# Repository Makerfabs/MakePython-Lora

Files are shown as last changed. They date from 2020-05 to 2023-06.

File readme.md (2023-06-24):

# MakePython Lora

```c++
/*
Version:		V2.1
Author:			Vincent
Create Date:	2020/7/24
Note:
2021/8/18		V2.1 Fix Lora Gateway 915M bug.
2020/12/11		V2.0 Now supply arduino lib: RadioLib
2022/8/15		V2.1 Update new RadioLib demo
*/
```

[toc]

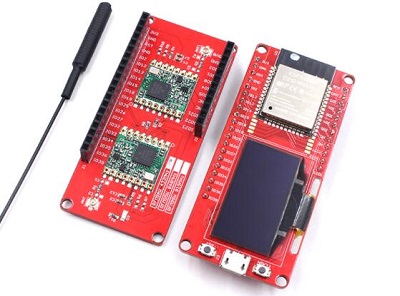
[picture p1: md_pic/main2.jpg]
main2


# Makerfabs

[Makerfabs home page](https://www.makerfabs.com/)

[Makerfabs Wiki](https://wiki.makerfabs.com/)

# Introduce

The Makepython Lora transceivers feature the LoRaTM long range modem that provides ultra-long range spread spectrum communication and high interference immunity whilst minimising current consumption.

Product Link ： [MakePython Lora](https://www.makerfabs.com/esp32-lora-gateway.html)

Wiki Link : [MakePython Lora Wiki](https://wiki.makerfabs.com/MaESP_ESP32_Lora_Gateway.html)

## Front

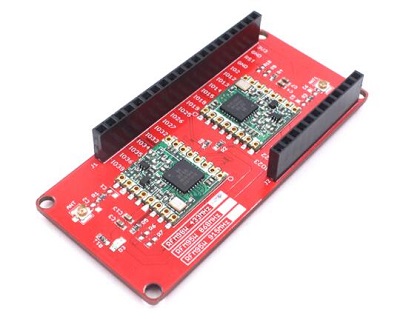
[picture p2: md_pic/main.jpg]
main


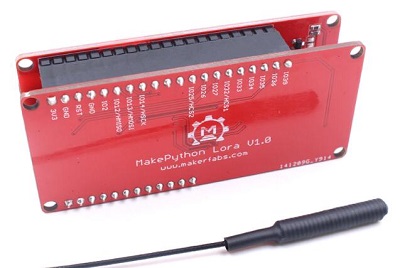
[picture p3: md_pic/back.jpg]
back


# RadioLib Example

## send_and_receive.ino

A demo for communicating with the standard Makerfabs LoraNode (MaLora).

All Lora Nodes use this Lora library: [RadioLib](https://github.com/jgromes/RadioLib)

**It is recommended to install from Arduino Library Manager and select the library version 4.6.0. RadioLib libraries after 5.0 need to add "RADIOLIB_" before some macro definitions.**

The current firmware is developed in RadioLib 4.6.0.

## MaLora

**MaLora** is Makerfabs Loranode.

Makerfabs Lora Node is a series of products based on Arduino Pro Mini (328P) + Lora(SX127X). 

Like Relay, AC Dimmer, MOSFET, etc.

For easy to use, UID and generic instructions are provided. Some of them are our previous products, but have not added UID yet. 

[MaLora](https://github.com/Makerfabs/Makerfabs_MaLora)

*We started with MicroPython, but the Lora library support was not good. There was also a failure to communicate with other Lora libraries. So we discontinued MicroPython maintenance, and subsequent Makerfabs Lora-related products use the agreed Lora library.*

## Test

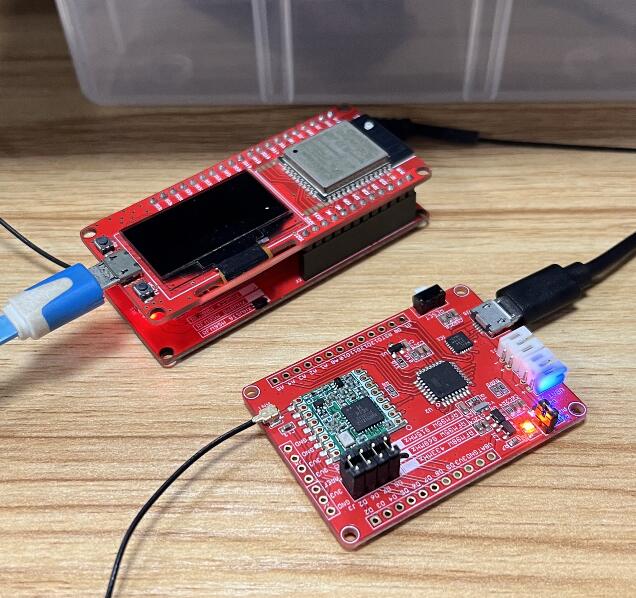
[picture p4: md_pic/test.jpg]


Communicates with a standard Lora Node. The code used by Maduino Lora Radio is in:

 [LoraNodeDemo](https://github.com/Makerfabs/Makerfabs_MaLora/tree/main/MaduinoLoraRadio/firmware/LoraNodeDemo)

Serial Monitor Display:

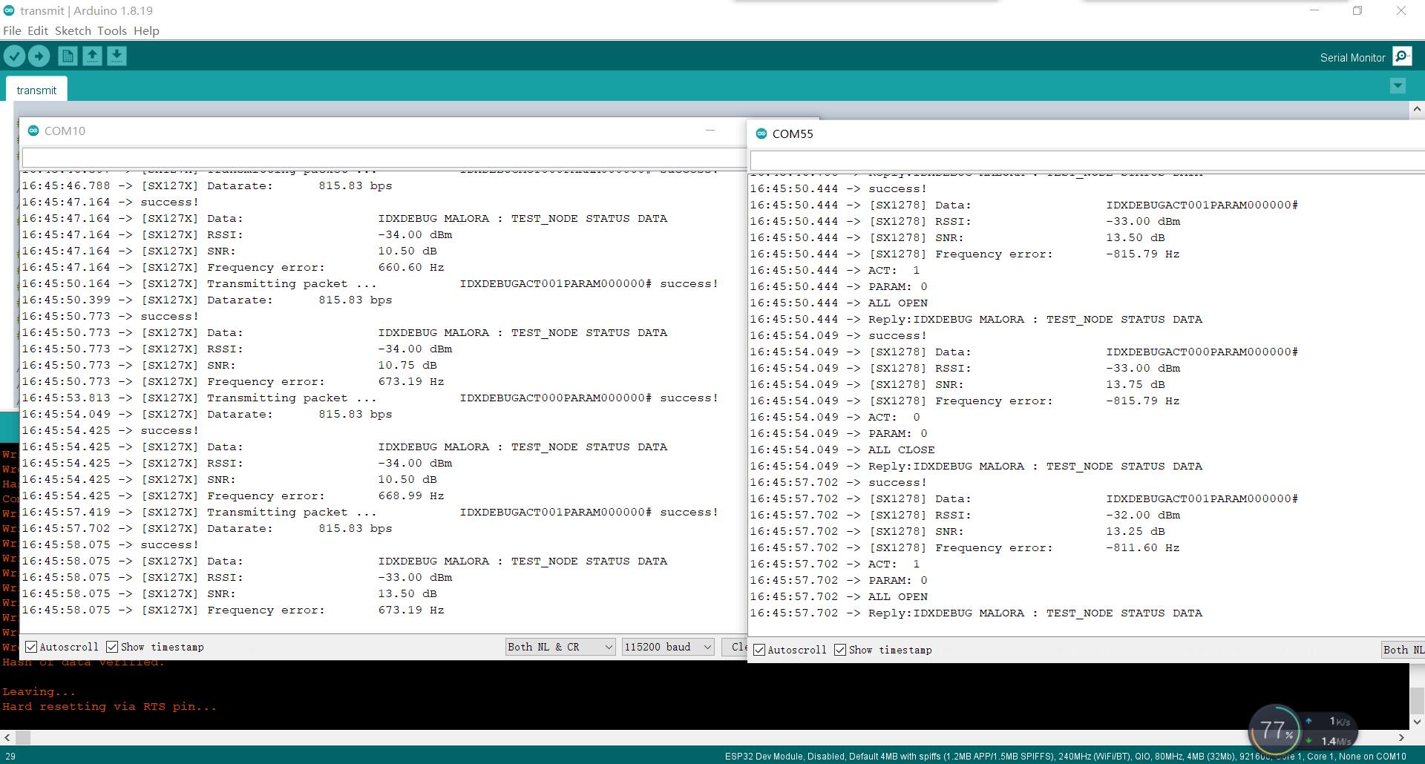
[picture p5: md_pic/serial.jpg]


# Related Tests

- Long distance Lora communication

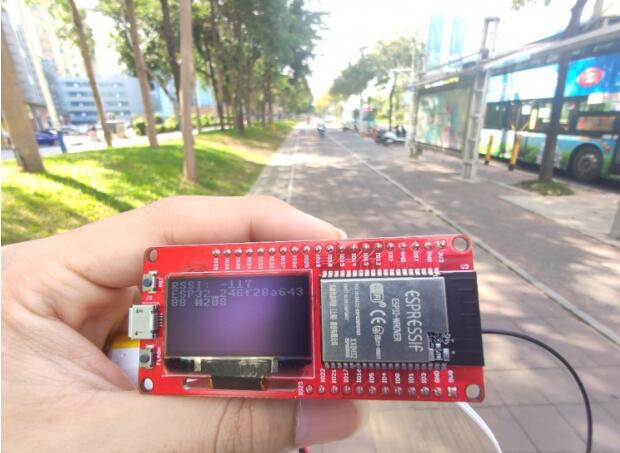
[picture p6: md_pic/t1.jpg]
t1


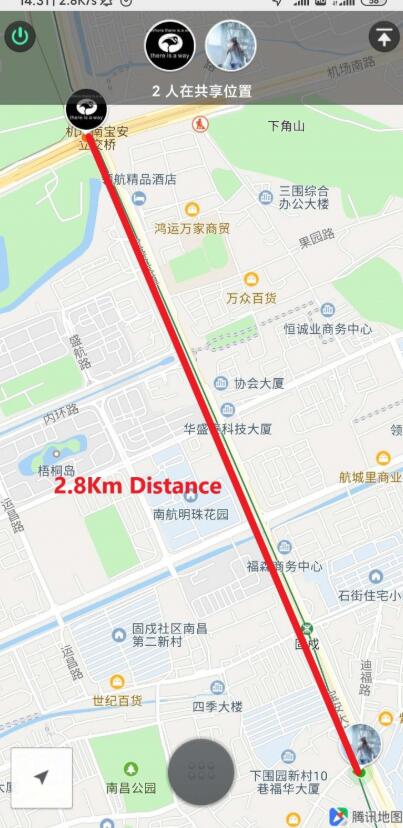
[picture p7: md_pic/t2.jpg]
t2


# Related Projects

## [Project_IoT Irrigation System](https://github.com/Makerfabs/Project_IoT-Irrigation-System)

- IoT agricultural irrigation experiment based on Lora communication.
- [YOUTUBE:Lora IoT Irrigation System - Outdoor Simulation Test](https://youtu.be/0mY6Ox0YvRk)

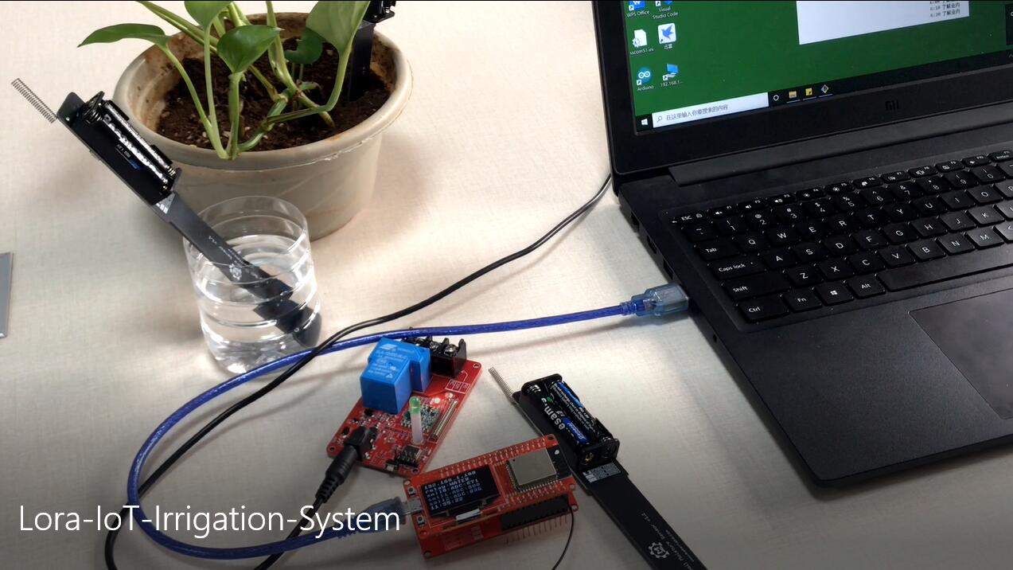
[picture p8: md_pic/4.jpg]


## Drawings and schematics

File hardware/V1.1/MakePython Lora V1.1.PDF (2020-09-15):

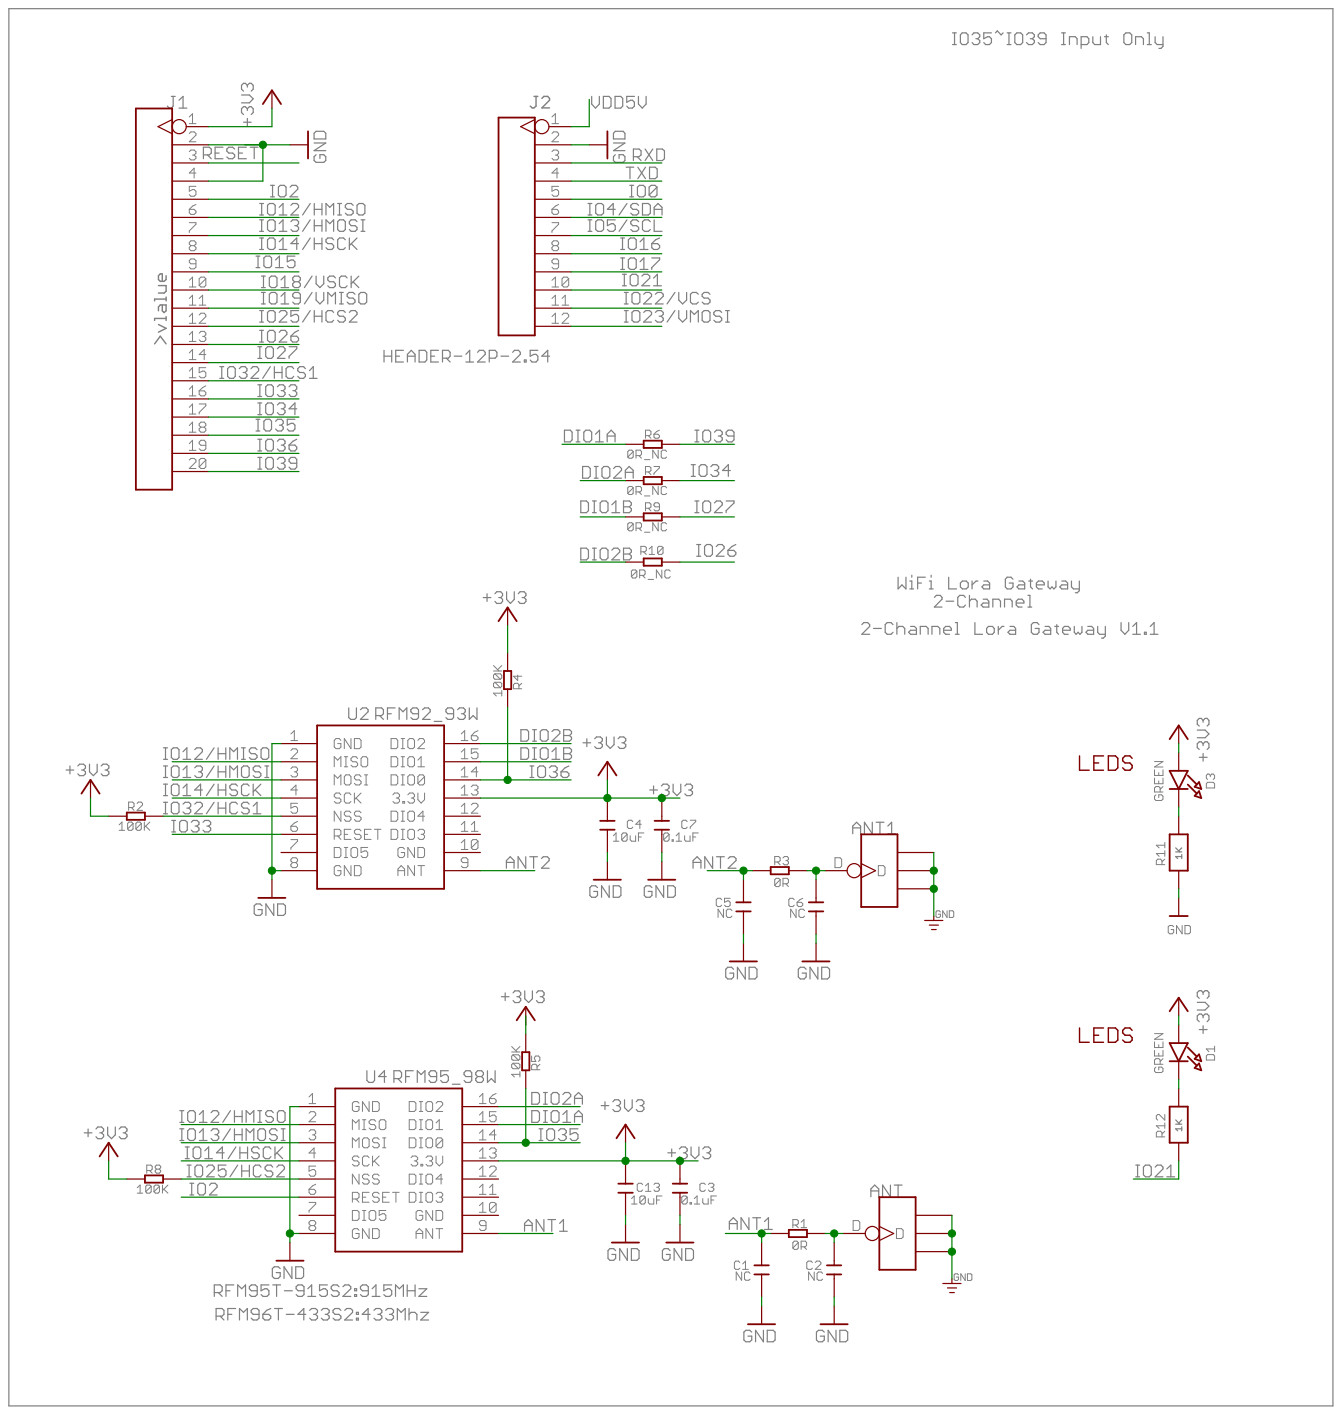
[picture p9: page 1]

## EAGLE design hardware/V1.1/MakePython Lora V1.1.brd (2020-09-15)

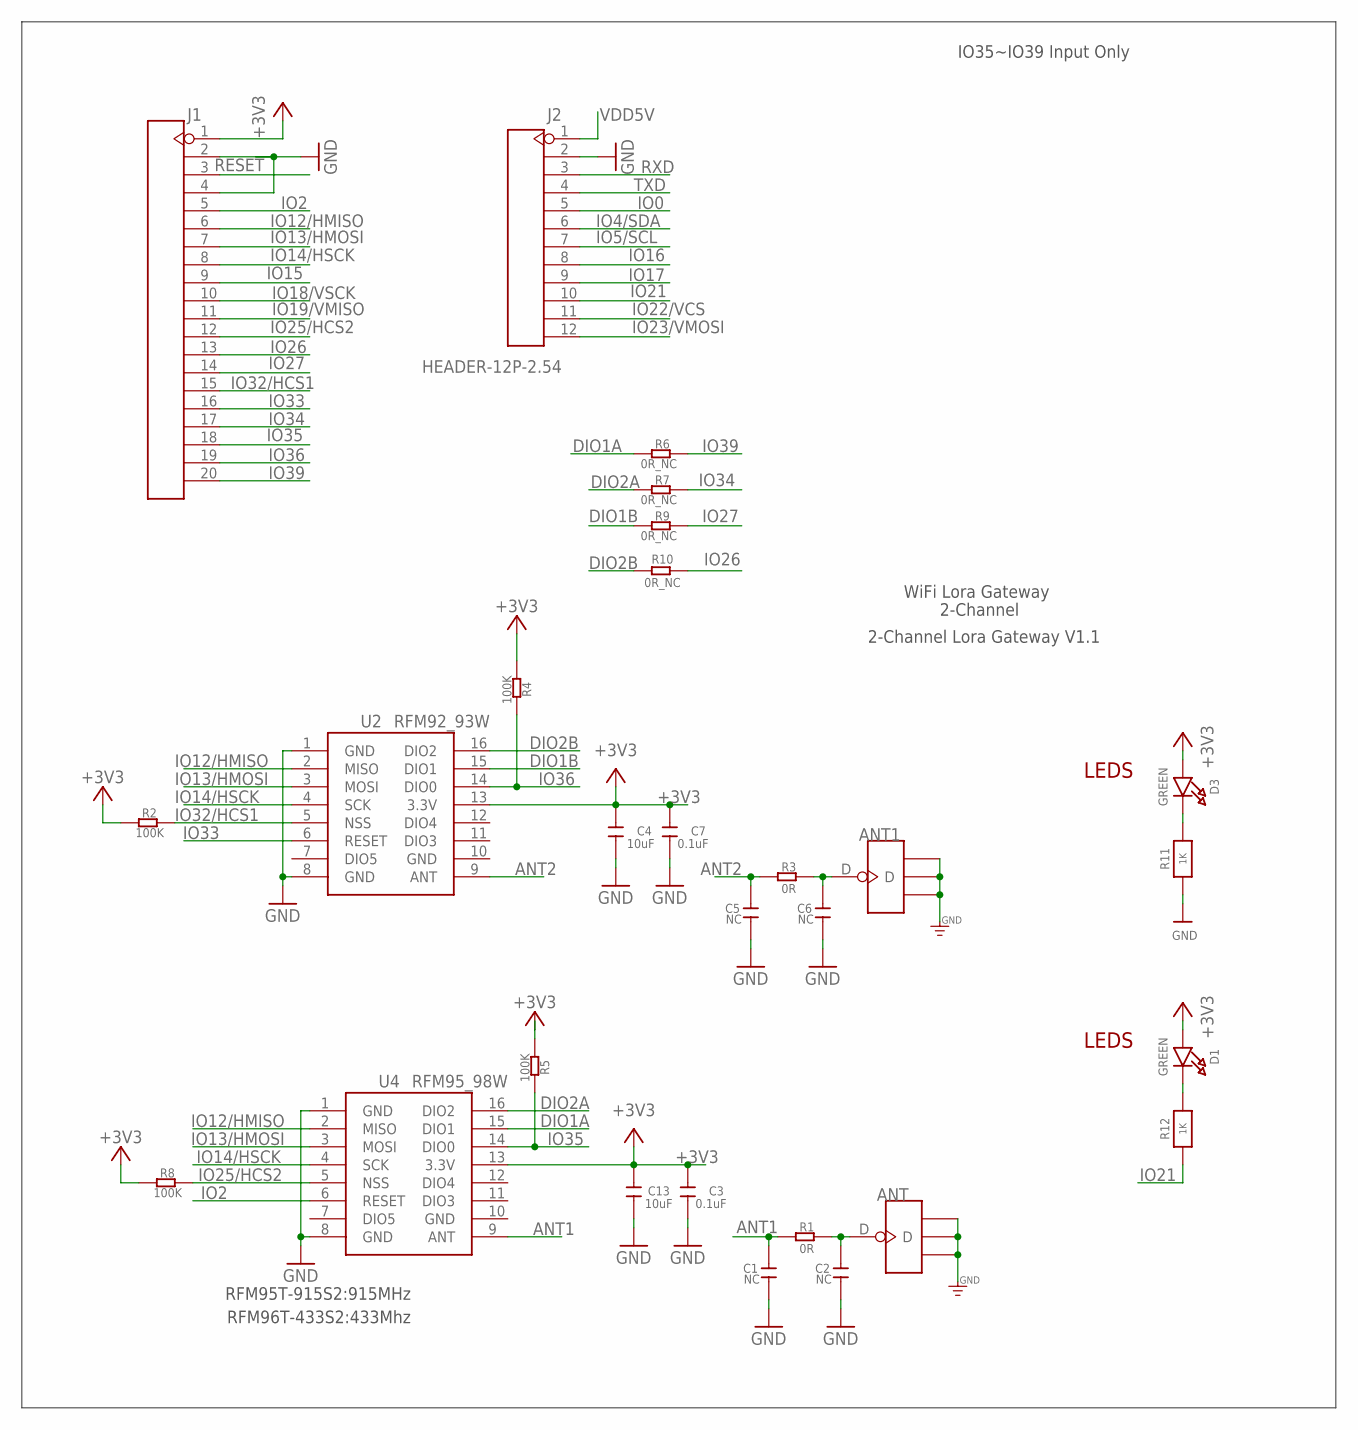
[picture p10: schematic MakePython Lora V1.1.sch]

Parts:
ANT, ANT1: ANTENNA-U-FL; 4P-U-FL
C1, C2, C5, C6: NC; DISCRETE_C0603
C3, C7: 0.1uF; 0603
C4, C13: 10uF; 0603
D1, D3: GREEN; CHIPLED_0805_NOOUTLINE
J1: HEADER-20P-2.54; 20P-2.54
J2: HEADER-12P-2.54; 12P-2.54
R1, R3: 0R; DISCRETE_R0603
R2, R4, R5, R8: 100K; R0603
R6, R7, R9, R10: 0R_NC; R0603
R11, R12: 1K; 0603-NO
U2: RFM92_93W
U4: RFM95_98W; RFM92_93W

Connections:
+3V3: C3.2, C4.2, C7.2, C13.2, D1.A, D3.A, J1.1, R2.2, R4.2, R5.2, R8.2, U2.13 (3.3V), U4.13 (3.3V)
ANT1: C1.2, R1.1, U4.9 (ANT)
ANT2: C5.2, R3.1, U2.9 (ANT)
DIO1A: R6.2, U4.15 (DIO1)
DIO1B: R9.2, U2.15 (DIO1)
DIO2A: R7.2, U4.16 (DIO2)
DIO2B: R10.2, U2.16 (DIO2)
GND: ANT.GND1, ANT.GND2, ANT.GND3, ANT1.GND1, ANT1.GND2, ANT1.GND3, C1.1, C2.1, C3.1, C4.1, C5.1, C6.1, C7.1, C13.1, J1.2, J1.4, J2.2, R11.1, U2.1 (GND), U2.8 (GND), U2.10 (GND), U4.1 (GND), U4.8 (GND), U4.10 (GND)
IO0: J2.5
IO2: J1.5, U4.6 (RESET)
IO4/SDA: J2.6
IO5/SCL: J2.7
IO12/HMISO: J1.6, U2.2 (MISO), U4.2 (MISO)
IO13/HMOSI: J1.7, U2.3 (MOSI), U4.3 (MOSI)
IO14/HSCK: J1.8, U2.4 (SCK), U4.4 (SCK)
IO15: J1.9
IO16: J2.8
IO17: J2.9
IO18/VSCK: J1.10
IO19/VMISO: J1.11
IO21: J2.10, R12.1
IO22/VCS: J2.11
IO23/VMOSI: J2.12
IO25/HCS2: J1.12, R8.1, U4.5 (NSS)
IO26: J1.13, R10.1
IO27: J1.14, R9.1
IO32/HCS1: J1.15, R2.1, U2.5 (NSS)
IO33: J1.16, U2.6 (RESET)
IO34: J1.17, R7.1
IO35: J1.18, R5.1, U4.14 (DIO0)
IO36: J1.19, R4.1, U2.14 (DIO0)
IO39: J1.20, R6.1
unnamed: ANT1.D, C6.2, R3.2
unnamed: ANT.D, C2.2, R1.2
unnamed: D1.C, R12.2
unnamed: D3.C, R11.2
RESET: J1.3
RXD: J2.3
TXD: J2.4
VDD5V: J2.1

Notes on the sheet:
RFM95T-915S2:915MHz
RFM96T-433S2:433Mhz
IO35~IO39 Input Only
WiFi Lora Gateway
2-Channel
2-Channel Lora Gateway V1.1
LEDS

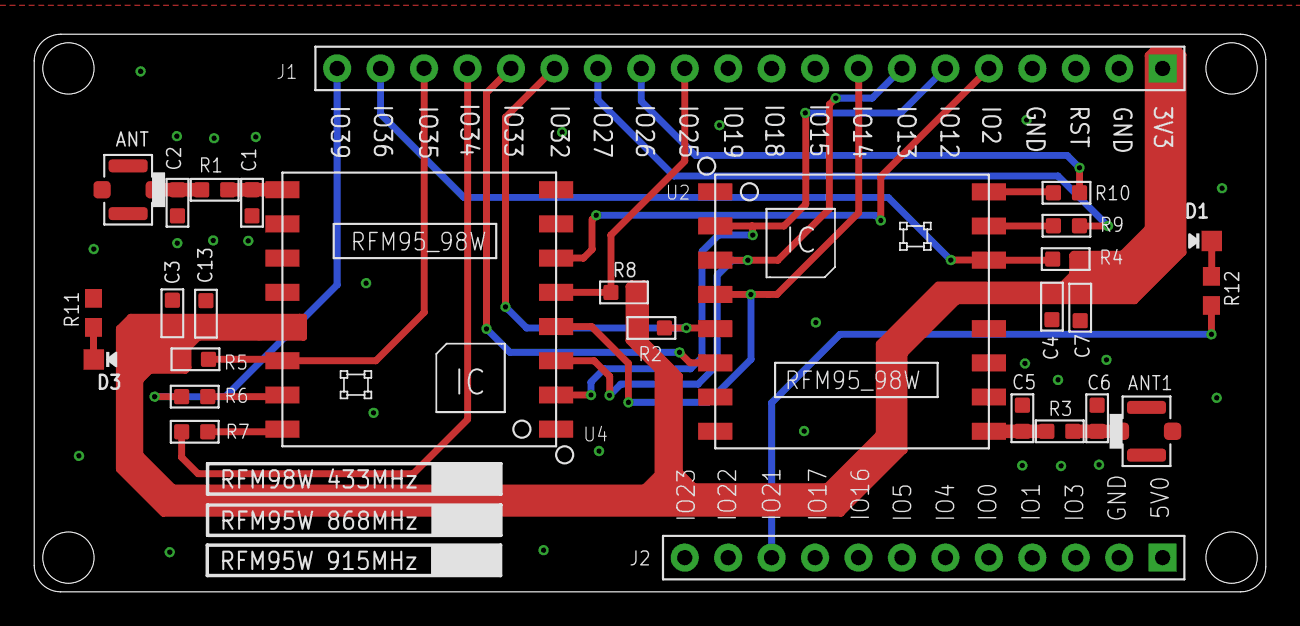
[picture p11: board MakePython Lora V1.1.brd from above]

Board: 2 copper layers, 72.0 x 32.6 mm, 29 parts (1 on the bottom side), 26 nets.

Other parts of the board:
U$1: MAKERFABS_0.3

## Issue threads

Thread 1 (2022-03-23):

Invalid version: 255 on Lora Gateway, 868 model

monfero, 2022-03-23:
I've uploaded the Code_868M version code to my 868 MakePython Lora but it throws an exception: Invalid version. The version is printed before and its value is 255.

```
version:  255
Traceback (most recent call last):
  File "main.py", line 12, in <module>
  File "test.py", line 42, in main
  File "controller_esp_lora_oled.py", line 82, in add_transceiver
  File "controller.py", line 65, in add_transceiver
  File "sx127x.py", line 99, in init
Exception: Invalid version.
MicroPython v1.10 on 2019-01-25; ESP32 module with ESP32
Type "help()" for more information.
```

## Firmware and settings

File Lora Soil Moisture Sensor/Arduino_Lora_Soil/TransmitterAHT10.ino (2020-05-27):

// LoRa 9x_TX
// -*- mode: C++ -*-
// Example sketch showing how to create a simple messaging client (transmitter)
// with the RH_RF95 class. RH_RF95 class does not provide for addressing or
// reliability, so you should only use RH_RF95 if you do not need the higher
// level messaging abilities.
// It is designed to work with the other example LoRa9x_RX

//Function:Transmit DHT11 to Lora
//Author: Charlin
//Date:2019/12/11

#include <SPI.h>
#include "RH_RF95.h"

#include "I2C_AHT10.h"
#include <Wire.h>
AHT10 humiditySensor;



#define RFM95_CS 10
#define RFM95_RST 4
#define RFM95_INT 2

// Change to 434.0 or other frequency, must match RX's freq!
#define RF95_FREQ 433.0

// Singleton instance of the radio driver
RH_RF95 rf95(RFM95_CS, RFM95_INT);

int sensorPin = A2;    // select the input pin for the potentiometer
int sensorValue = 0;  // variable to store the value coming from the sensor

void setup() 
{
  pinMode(RFM95_RST, OUTPUT);
  digitalWrite(RFM95_RST, HIGH);
  pinMode(9, INPUT);
  
  //while (!Serial);
  Serial.begin(115200);
  delay(100);

  Wire.begin(); //Join I2C bus
  //Check if the AHT10 will acknowledge
  if (humiditySensor.begin() == false)
  {
    Serial.println("AHT10 not detected. Please check wiring. Freezing.");
    //while (1);
  }
  else
    Serial.println("AHT10 acknowledged.");
  
  Serial.println("Marduino LoRa TX Test!");

  // manual reset
  digitalWrite(RFM95_RST, LOW);
  delay(10);
  digitalWrite(RFM95_RST, HIGH);
  delay(10);

  while (!rf95.init()) {
    Serial.println("LoRa radio init failed");
    while (1);
  }
  Serial.println("LoRa radio init OK!");

  // Defaults after init are 434.0MHz, modulation GFSK_Rb250Fd250, +13dbM
  if (!rf95.setFrequency(RF95_FREQ)) {
    Serial.println("setFrequency failed");
    while (1);
  }
  Serial.print("Set Freq to: "); Serial.println(RF95_FREQ);
  
  // Defaults after init are 434.0MHz, 13dBm, Bw = 125 kHz, Cr = 4/5, Sf = 128chips/symbol, CRC on

  // The default transmitter power is 13dBm, using PA_BOOST.
  // If you are using RFM95/96/97/98 modules which uses the PA_BOOST transmitter pin, then 
  // you can set transmitter powers from 5 to 23 dBm:
  rf95.setTxPower(23, false);
}

int16_t packetnum = 0;  // packet counter, we increment per xmission
float temperature=0.0;//
float humidity=0.0;

void loop()
{
  sensorValue = analogRead(sensorPin);
  //If a new measurement is available
  if (humiditySensor.available() == true)
  {
    //Get the new temperature and humidity value
    temperature = humiditySensor.getTemperature();
    humidity = humiditySensor.getHumidity();

    //Print the results
    Serial.print("Temperature: ");
    Serial.print(temperature, 2);
    Serial.print(" C\t");
    Serial.print("Humidity: ");
    Serial.print(humidity, 2);
    Serial.print("% RH");

    Serial.println();
  }
    // Check if any reads failed and exit early (to try again).
  if (isnan(humidity) || isnan(temperature)) {
    Serial.println(F("Failed to read from AHT sensor!"));
    //return;
  }

  //Serial.print(F("Humidity: "));
  //Serial.print(humidity);
  //Serial.print(F("%  Temperature: "));
  //Serial.print(temperature);
  //Serial.println("Humidity is " + (String)humidity);
  //Serial.println("Temperature is " + (String)temperature);

  String message = "#"+(String)packetnum+" Humidity:"+(String)humidity+"% Temperature:"+(String)temperature+"C"+" ADC:"+(String)sensorValue;
  Serial.println(message);
  packetnum++;
  Serial.println("Transmit: Sending to rf95_server");
  
  // Send a message to rf95_server

  uint8_t radioPacket[message.length()+1];
  message.toCharArray(radioPacket, message.length()+1);
  
  radioPacket[message.length()+1]= '\0';

  
  Serial.println("Sending..."); delay(10);
  rf95.send((uint8_t *)radioPacket, message.length()+1); 
  Serial.println("Waiting for packet to complete..."); delay(10);
  rf95.waitPacketSent();
  // Now wait for a reply
  uint8_t buf[RH_RF95_MAX_MESSAGE_LEN];
  uint8_t len = sizeof(buf);

  Serial.println("Waiting for reply..."); delay(10);
  if (rf95.waitAvailableTimeout(2000))
  { 
    // Should be a reply message for us now   
    if (rf95.recv(buf, &len))
   {
      Serial.print("Got reply: ");
      Serial.println((char*)buf);
      Serial.print("RSSI: ");
      Serial.println(rf95.lastRssi(), DEC);    
    }
    else
    {
      Serial.println("Receive failed");
    }
  }
  else
  {
    Serial.println("No reply, is there a listener around?");
  }
  delay(10000);//unit: ms
}

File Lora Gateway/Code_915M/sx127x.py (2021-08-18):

from time import sleep 
import gc
import config_lora


PA_OUTPUT_RFO_PIN = 0
PA_OUTPUT_PA_BOOST_PIN = 1


# registers
REG_FIFO = 0x00
REG_OP_MODE = 0x01
REG_FRF_MSB = 0x06
REG_FRF_MID = 0x07
REG_FRF_LSB = 0x08
REG_PA_CONFIG = 0x09
REG_LNA = 0x0c
REG_FIFO_ADDR_PTR = 0x0d

REG_FIFO_TX_BASE_ADDR = 0x0e
FifoTxBaseAddr = 0x00
# FifoTxBaseAddr = 0x80

REG_FIFO_RX_BASE_ADDR = 0x0f  
FifoRxBaseAddr = 0x00 
REG_FIFO_RX_CURRENT_ADDR = 0x10
REG_IRQ_FLAGS_MASK = 0x11
REG_IRQ_FLAGS = 0x12
REG_RX_NB_BYTES = 0x13
REG_PKT_RSSI_VALUE = 0x1a
REG_PKT_SNR_VALUE = 0x1b
REG_MODEM_CONFIG_1 = 0x1d
REG_MODEM_CONFIG_2 = 0x1e
REG_PREAMBLE_MSB = 0x20
REG_PREAMBLE_LSB = 0x21
REG_PAYLOAD_LENGTH = 0x22
REG_FIFO_RX_BYTE_ADDR = 0x25
REG_MODEM_CONFIG_3 = 0x26
REG_RSSI_WIDEBAND = 0x2c
REG_DETECTION_OPTIMIZE = 0x31
REG_DETECTION_THRESHOLD = 0x37
REG_SYNC_WORD = 0x39
REG_DIO_MAPPING_1 = 0x40
REG_VERSION = 0x42

# modes
MODE_LONG_RANGE_MODE = 0x80  # bit 7: 1 => LoRa mode
MODE_SLEEP = 0x00
MODE_STDBY = 0x01
MODE_TX = 0x03
MODE_RX_CONTINUOUS = 0x05
MODE_RX_SINGLE = 0x06

# PA config
PA_BOOST = 0x80

# IRQ masks
IRQ_TX_DONE_MASK = 0x08
IRQ_PAYLOAD_CRC_ERROR_MASK = 0x20
IRQ_RX_DONE_MASK = 0x40
IRQ_RX_TIME_OUT_MASK = 0x80

# Buffer size
MAX_PKT_LENGTH = 255


class SX127x:
    
    # The controller can be ESP8266, ESP32, Raspberry Pi, or a PC.
    # The controller needs to provide an interface consisted of:
    # 1. a SPI, with transfer function.
    # 2. a reset pin, with low(), high() functions.
    # 3. IRQ pinS , to be triggered by RFM96W's DIO0~5 pins. These pins each has two functions:
    #   3.1 set_handler_for_irq_on_rising_edge() 
    #   3.2 detach_irq()
    # 4. a function to blink on-board LED. 

    #Correct set  
    def __init__(self,
                 name = 'SX127x',
                 parameters = {'frequency': 915E6, 'tx_power_level': 2, 'signal_bandwidth': 125E3, 
                               'spreading_factor': 7, 'coding_rate': 8, 'preamble_length': 8, 
                               'implicitHeader': True, 'sync_word': 0x12, 'enable_CRC': True},
                 onReceive = None):

    # Old error code, need change sf ,implicitheader, CRC.    
    # def __init__(self,
    #              name = 'SX127x',
    #              parameters = {'frequency': 915E6, 'tx_power_level': 24, 'signal_bandwidth': 125E3, 
    #                            'spreading_factor': 11, 'coding_rate': 8, 'preamble_length': 8, 
    #                            'implicitHeader': False, 'sync_word': 0x12, 'enable_CRC': False},
    #              onReceive = None):
                 
        self.name = name
        self.parameters = parameters 
        self._onReceive = onReceive        
        self._lock = False
        
     
    def init(self, parameters = None):
        if parameters: self.parameters = parameters
            
        # check version
        version = self.readRegister(REG_VERSION)
        print('version: ', version)
        if version != 0x12:
            raise Exception('Invalid version.')
            
        
        # put in LoRa and sleep mode
        self.sleep()
        
        
        # config
        self.setFrequency(self.parameters['frequency'])
        self.setSignalBandwidth(self.parameters['signal_bandwidth'])

        # set LNA boost
        self.writeRegister(REG_LNA, self.readRegister(REG_LNA) | 0x03)

        # set auto AGC
        self.writeRegister(REG_MODEM_CONFIG_3, 0x04)

        self.setTxPower(self.parameters['tx_power_level'])
        self._implicitHeaderMode = None
        self.implicitHeaderMode(self.parameters['implicitHeader'])
        self.setSpreadingFactor(self.parameters['spreading_factor'])
        self.setCodingRate(self.parameters['coding_rate'])
        self.setPreambleLength(self.parameters['preamble_length'])
        self.setSyncWord(self.parameters['sync_word'])
        self.enableCRC(self.parameters['enable_CRC'])
        
        # set LowDataRateOptimize flag if symbol time > 16ms (default disable on reset)
        # self.writeRegister(REG_MODEM_CONFIG_3, self.readRegister(REG_MODEM_CONFIG_3) & 0xF7)  # default disable on reset
        
        #if 1000 / (self.parameters['signal_bandwidth'] / 2**self.parameters['spreading_factor']) > 16:
        #    self.writeRegister(REG_MODEM_CONFIG_3, self.readRegister(REG_MODEM_CONFIG_3) | 0x08)
        
        # set base addresses
        self.writeRegister(REG_FIFO_TX_BASE_ADDR, FifoTxBaseAddr)
        self.writeRegister(REG_FIFO_RX_BASE_ADDR, FifoRxBaseAddr)
        
        self.standby() 
              
        
    def beginPacket(self, implicitHeaderMode = False):        
        self.standby()
        self.implicitHeaderMode(implicitHeaderMode)
 
        # reset FIFO address and paload length 
        self.writeRegister(REG_FIFO_ADDR_PTR, FifoTxBaseAddr)
        self.writeRegister(REG_PAYLOAD_LENGTH, 0)
     

    def endPacket(self):
        # put in TX mode
        self.writeRegister(REG_OP_MODE, MODE_LONG_RANGE_MODE | MODE_TX)

        # wait for TX done, standby automatically on TX_DONE
        while (self.readRegister(REG_IRQ_FLAGS) & IRQ_TX_DONE_MASK) == 0:
            pass 
            
        # clear IRQ's
        self.writeRegister(REG_IRQ_FLAGS, IRQ_TX_DONE_MASK)
        
        self.collect_garbage()
   

    def write(self, buffer):
        currentLength = self.readRegister(REG_PAYLOAD_LENGTH)
        size = len(buffer)

        # check size
        size = min(size, (MAX_PKT_LENGTH - FifoTxBaseAddr - currentLength))

        # write data
        for i in range(size):
            self.writeRegister(REG_FIFO, buffer[i])
        
        # update length        
        self.writeRegister(REG_PAYLOAD_LENGTH, currentLength + size)
        return size

        
    def aquire_lock(self, lock = False):        
        if not config_lora.IS_MICROPYTHON:  # MicroPython is single threaded, doesn't need lock.
            if lock:
                while self._lock: pass
                self._lock = True
            else:
                self._lock = False
            
            
    def println(self, string, implicitHeader = False):        
        self.aquire_lock(True)  # wait until RX_Done, lock and begin writing.
        
        self.beginPacket(implicitHeader) 
        self.write(string.encode())
        self.endPacket()  

        self.aquire_lock(False) # unlock when done writing

    
    def getIrqFlags(self):
        irqFlags = self.readRegister(REG_IRQ_FLAGS)
        self.writeRegister(REG_IRQ_FLAGS, irqFlags)
        return irqFlags

        
    def packetRssi(self):
        return (self.readRegister(REG_PKT_RSSI_VALUE) - (164 if self._frequency < 868E6 else 157))


    def packetSnr(self):
        return (self.readRegister(REG_PKT_SNR_VALUE)) * 0.25
        
       
    def standby(self):
        self.writeRegister(REG_OP_MODE, MODE_LONG_RANGE_MODE | MODE_STDBY)
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

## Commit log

2020-05-27 Create Lora Soil Moisture Sensor
2020-07-24 create readme‘
2020-09-15 add hardware
    [MakePython Lora V1.1.brd, MakePython Lora V1.1.sch]
2020-12-11 add arduino lib example
2022-02-15 hardware notice
    0Ω±5% 0603 resistors at R6,R7,R9,R10 when using RadioLib(RadioLib library requires)

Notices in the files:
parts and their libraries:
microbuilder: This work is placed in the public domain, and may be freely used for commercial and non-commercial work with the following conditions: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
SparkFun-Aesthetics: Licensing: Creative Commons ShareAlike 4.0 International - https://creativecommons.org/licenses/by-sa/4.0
